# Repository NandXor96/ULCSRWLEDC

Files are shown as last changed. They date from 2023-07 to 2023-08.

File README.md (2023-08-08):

# ULCSRWLEDC
Ultra Low Cost Sound Reactive WLED Controller

## Features

- Small size
- Cheap components
- ICS-43434 MEMS Microphone (optional)
- MOSFET as "Relay"
- Mini Blade Fuse
- Solder Pads instead of Screw Terminal Blocks

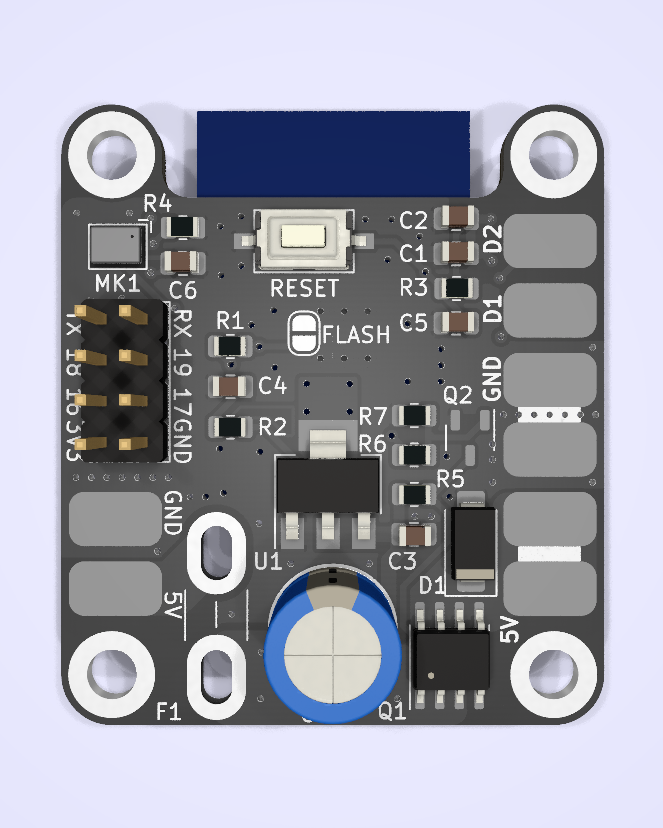
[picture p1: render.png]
Rendered picture of pcb


## BOM

| Reference | Value | Comment | Estimated Cost per piece |
|---|---|---|---|
| C1, C6 | 100nF | 0805 MLCC | 0.01€ |
| C2 | 10 - 22uF | 0805 MLCC | 0.10€ |
| C3, C4* | 22uF | 0805 MLCC | 0.10€ |
| C5 | 1uF | 0805 MLCC | 0.05€ |
| C7 | >=300uF | Electrolytic Cap D8.0 P3.5 | 0.15€ |
| D1 | SS14 | Schottky | 0.05€ |
| F1 | 2 - 10A | Mini Blade Fuse | 0.50€ |
| MK1** | ICS43434 | optional MEMS Microphone | 0.95 - 2.90€ |
| Q1 | - | SOIC-8 PMOS according to your needs - f.e. IRF7410 | 0.70 - 1.50€ |
| Q2 | - | SOT-23-3 NMOS according to your needs - f.e. IRLML6244 | 0.05 - 0.50€ |
| R1, R3, R5, R7 | 10k | 0805 Resistor | 0.01€ |
| R4 | 100k | 0805 Resistor | 0.01€ |
| R6 | 300R | 0805 Resistor | 0.01€ |
| R2* | 0.03-1R | optional 0805 Resistor | - |
| SW1 | - | Reset Switch SMD 6x3.5mm - f.e. PTS636 | 0.05 - 0.50€ |
| U1 | AMS1117-3.3 | SOT-223-3 LDO | 0.05 - 0.50€ | 
| U2 | ESP-WROOM-32 | ESP32-Module with antenna | 2.85€ |
| PCB | - | JLCPCB | 1.20€ |
|------|------|------|------|
|  |  |  | 5.12 - 10.89€ |

*If you have problems with the stability of the LDO you have two options:
1. Cut the trace resistance between R2 and try some 0805 resistors from 0.03-1ohm.
2. Choose tantal for C4 and bridge R2

** You can build it without the microphone. Then you don't need C6, R4 and MK1.

## Assembly

To assemble the PCB, I recommend using a hot plate or soldering oven for the upper side, and hand-soldering for the ESP32 on the back.
**Preheat** the PCB before soldering anything by hand and use a **powerful soldering iron**!  
Do NOT use a very small tip!

## Disclaimer

The circuit board provided on this GitHub repository is offered "as is," without any warranties or guarantees of any kind. By accessing and utilizing this circuit board, you acknowledge and agree that you do so at your own risk.

The creator and contributor of this repository, shall not be held responsible or liable for any damages, losses, or injuries that may occur as a result of building and / or using this circuit board. This includes but is not limited to any direct, indirect, consequential, or incidental damages.

Electricity is dangerous. Only attempt this project if you know what you're doing.

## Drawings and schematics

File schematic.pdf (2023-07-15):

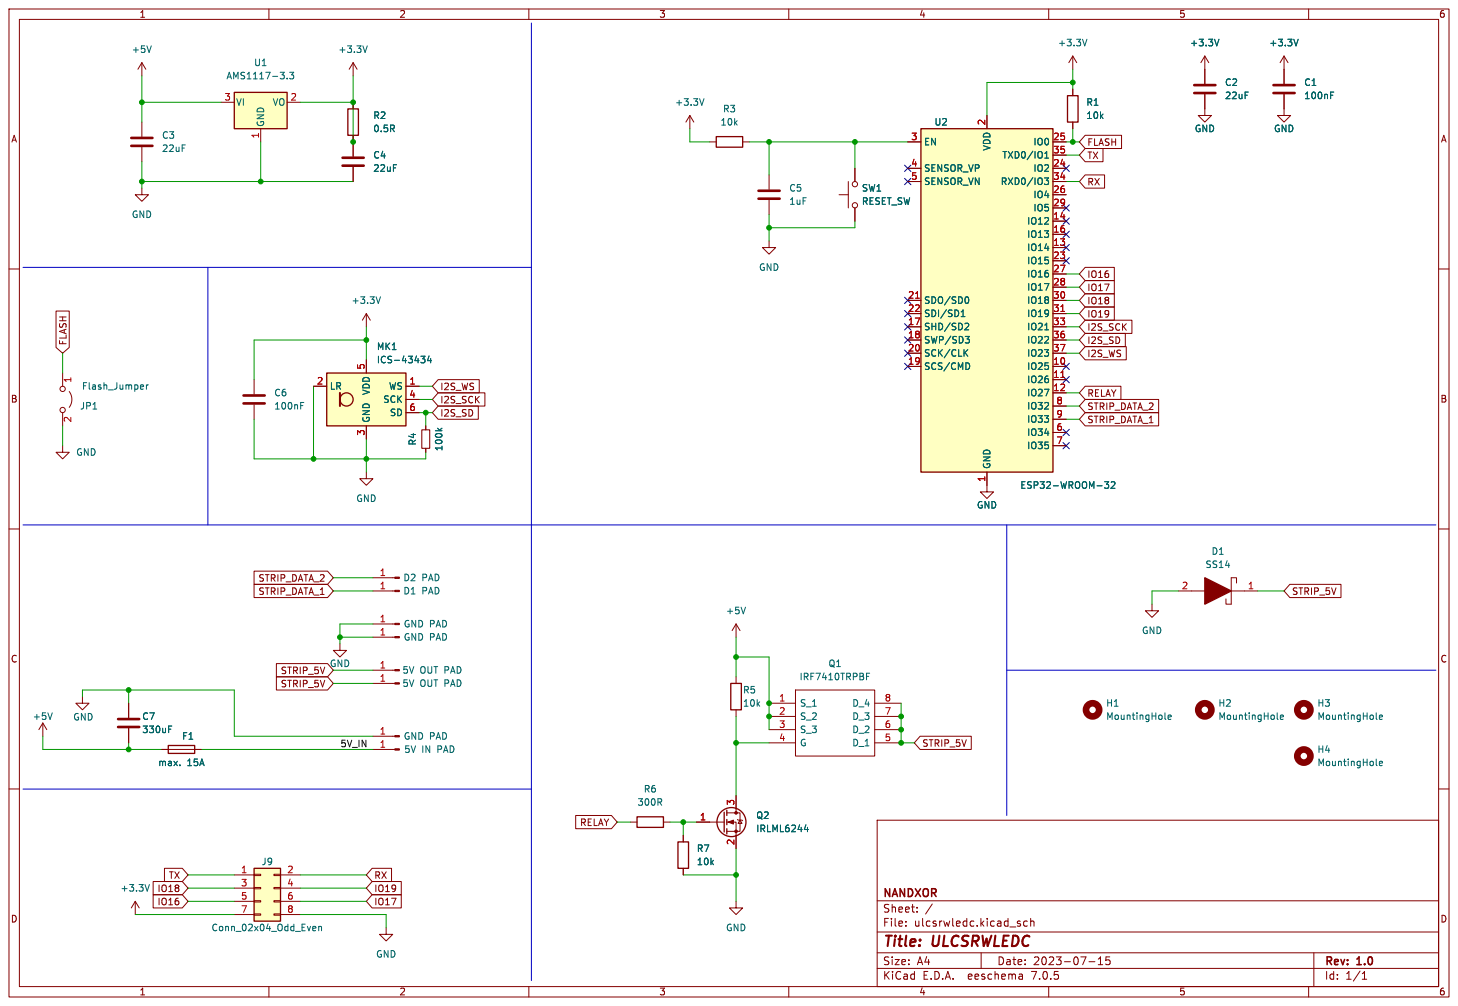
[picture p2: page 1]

File: ulcsrwledc.kicad_sch Sheet: / NANDXOR GND

2 SCK/CLK 20 SDO/SD0 21 SDI/SD1 22

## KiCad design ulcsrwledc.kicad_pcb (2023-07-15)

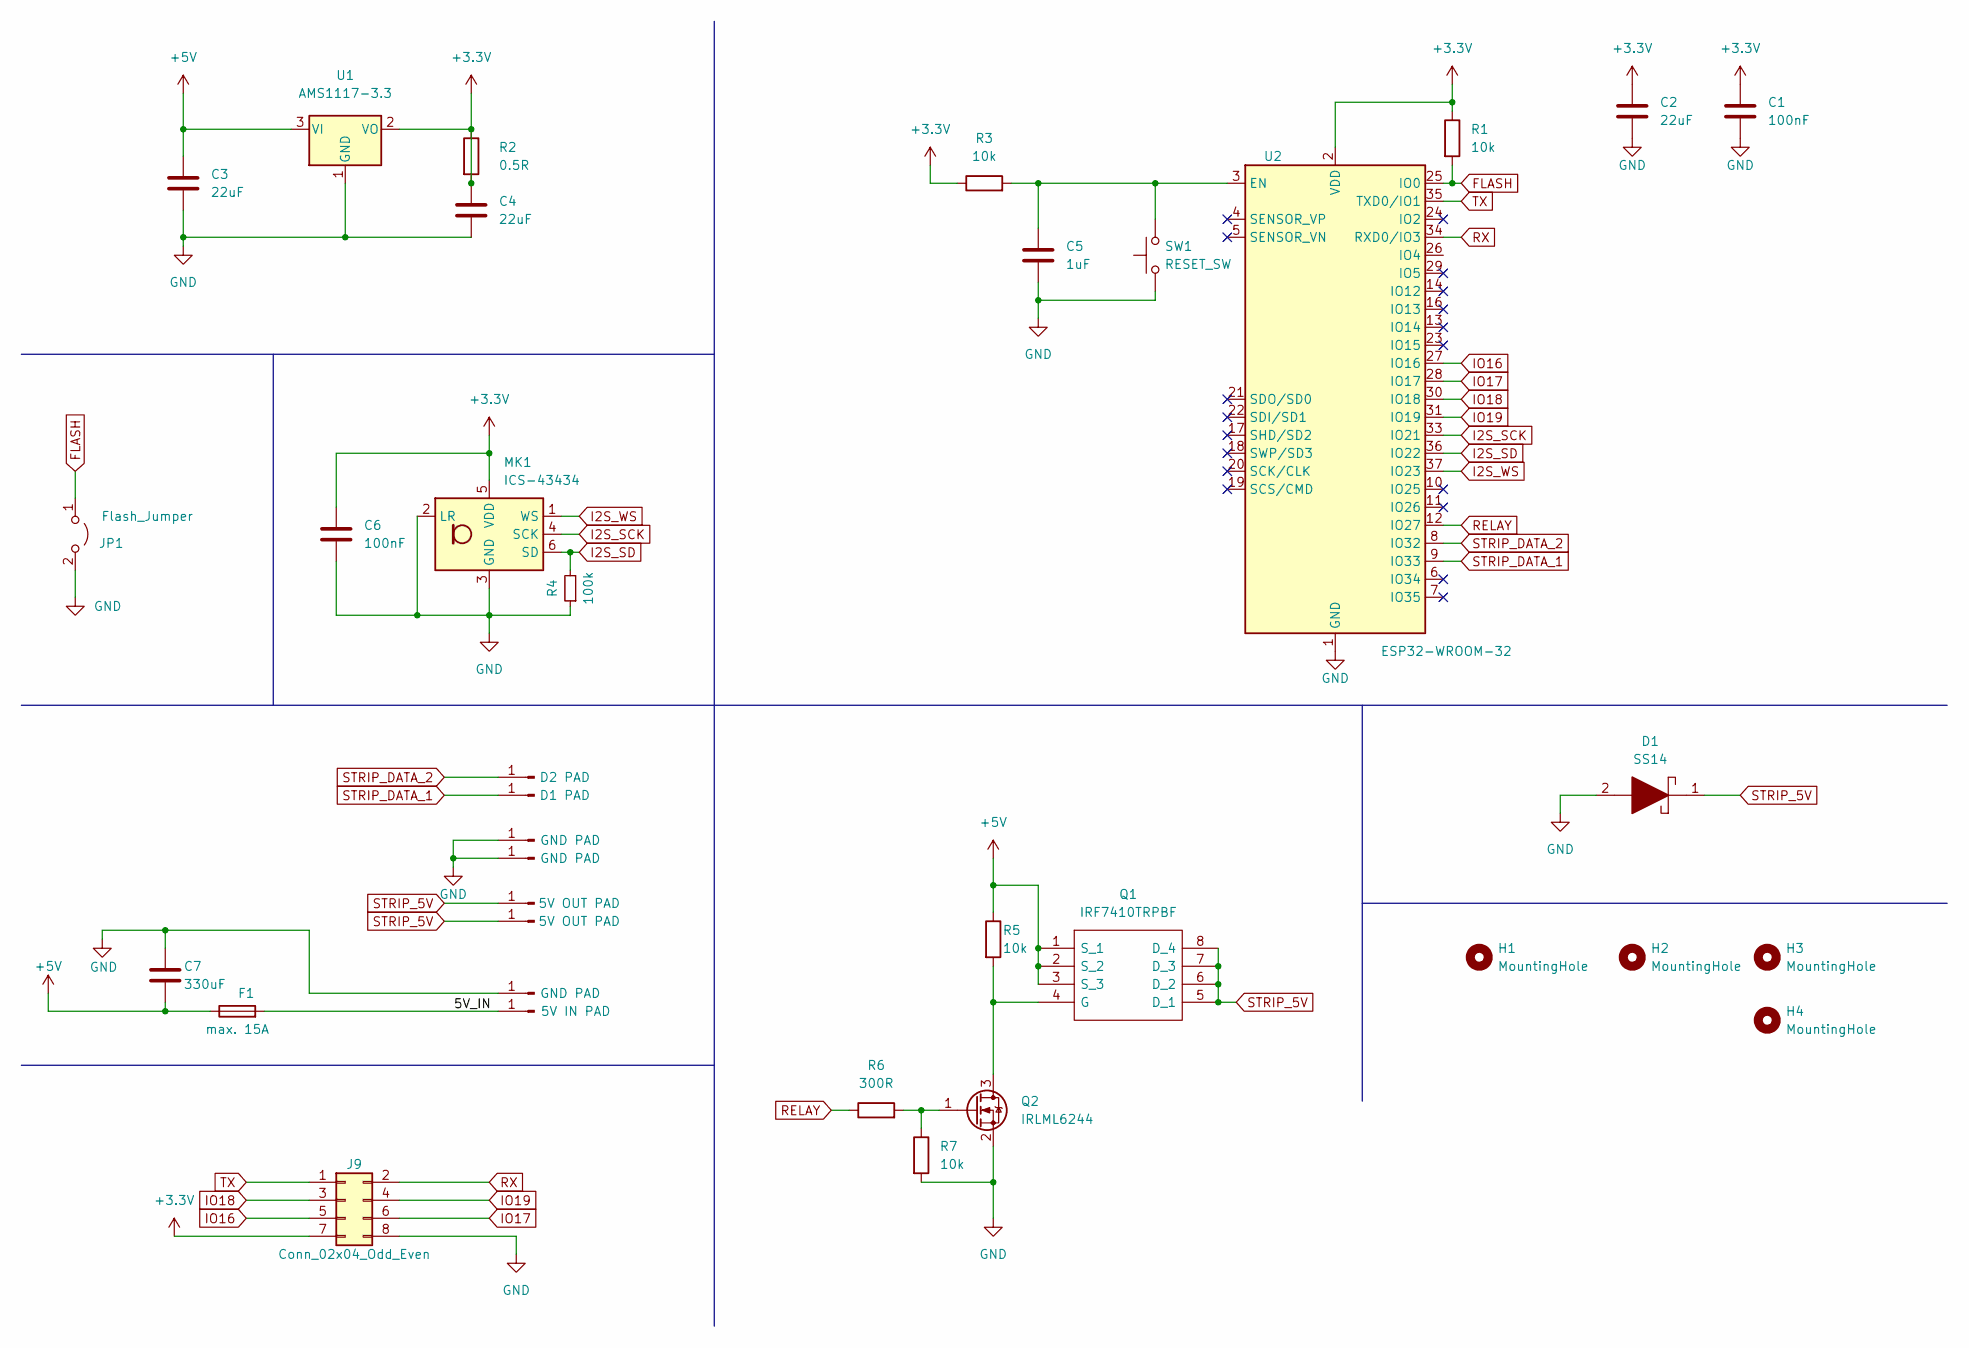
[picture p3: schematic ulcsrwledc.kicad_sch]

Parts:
C1, C6: 100nF; C_0805_2012Metric
C2, C3, C4: 22uF; C_0805_2012Metric
C5: 1uF; C_0805_2012Metric
C7: 330uF; CP_Radial_D8.0mm_P3.50mm
D1: SS14; D_SMA
F1: max. 15A; Fuse_Blade_Mini_directSolder
H1, H2, H3, H4: MountingHole; MountingHole_3.2mm_M3_DIN965_Pad_TopBottom
J1, J4: 5V OUT PAD; SolderWirePad_1x01_SMD_3x6mm
J2: D1 PAD; SolderWirePad_1x01_SMD_3x6mm
J3, J6, J7: GND PAD; SolderWirePad_1x01_SMD_3x6mm
J5: D2 PAD; SolderWirePad_1x01_SMD_3x6mm
J8: 5V IN PAD; SolderWirePad_1x01_SMD_3x6mm
J9: Conn_02x04_Odd_Even; PinHeader_2x04_P2.54mm_Vertical
JP1: Flash_Jumper; SolderJumper-2_P1.3mm_Open_RoundedPad1.0x1.5mm
MK1: ICS-43434; InvenSense_ICS-43434-6_3.5x2.65mm
Q1: IRF7410TRPBF; SO-8_3.9x4.9mm_P1.27mm
Q2: IRLML6244; SOT-23-3
R1, R3, R5, R7: 10k; R_0805_2012Metric
R2: 0.5R; R_0805_2012Metric
R4: 100k; R_0805_2012Metric
R6: 300R; R_0805_2012Metric
SW1: RESET_SW; SW_Tactile_SPST_NO_Straight_CK_PTS636Sx25SMTRLFS
U1: AMS1117-3.3; SOT-223-3_TabPin2
U2: ESP32-WROOM-32

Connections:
+3.3V: C1.2, C2.1, C4.1, C6.1, J9.7, MK1.5 (VDD), R1.1, R2.1, R2.2, R3.1, U1.2 (VO), U2.2 (VDD)
+5V: C3.1, C7.1, F1.1, Q1.1 (S_1), Q1.2 (S_2), Q1.3 (S_3), R5.1, U1.3 (VI)
/5V_IN: F1.2, J8.1
FLASH: JP1.1 (A), R1.2, U2.25 (IO0)
GND: C1.1, C2.2, C3.2, C4.2, C5.2, C6.2, C7.2, D1.2, J3.1, J6.1, J7.1, J9.8, JP1.2 (B), MK1.2 (LR), MK1.3 (GND), Q2.2 (S), R4.1, R7.2, SW1.1, U1.1 (GND), U2.1 (GND), U2.15 (GND), U2.38 (GND), U2.39 (GND)
I2S_SCK: MK1.4 (SCK), U2.33 (IO21)
I2S_SD: MK1.6 (SD), R4.2, U2.36 (IO22)
I2S_WS: MK1.1 (WS), U2.37 (IO23)
IO16: J9.5, U2.27 (IO16)
IO17: J9.6, U2.28 (IO17)
IO18: J9.3, U2.30 (IO18)
IO19: J9.4, U2.31 (IO19)
unnamed: Q1.4 (G), Q2.3 (D), R5.2
unnamed: Q2.1 (G), R6.2, R7.1
unnamed: C5.1, R3.2, SW1.2, U2.3 (EN)
RELAY: R6.1, U2.12 (IO27)
RX: J9.2, U2.34 (RXD0/IO3)
STRIP_5V: D1.1, J1.1, J4.1, Q1.5 (D_1), Q1.6 (D_2), Q1.7 (D_3), Q1.8 (D_4)
STRIP_DATA_1: J2.1, U2.9 (IO33)
STRIP_DATA_2: J5.1, U2.8 (IO32)
TX: J9.1, U2.35 (TXD0/IO1)

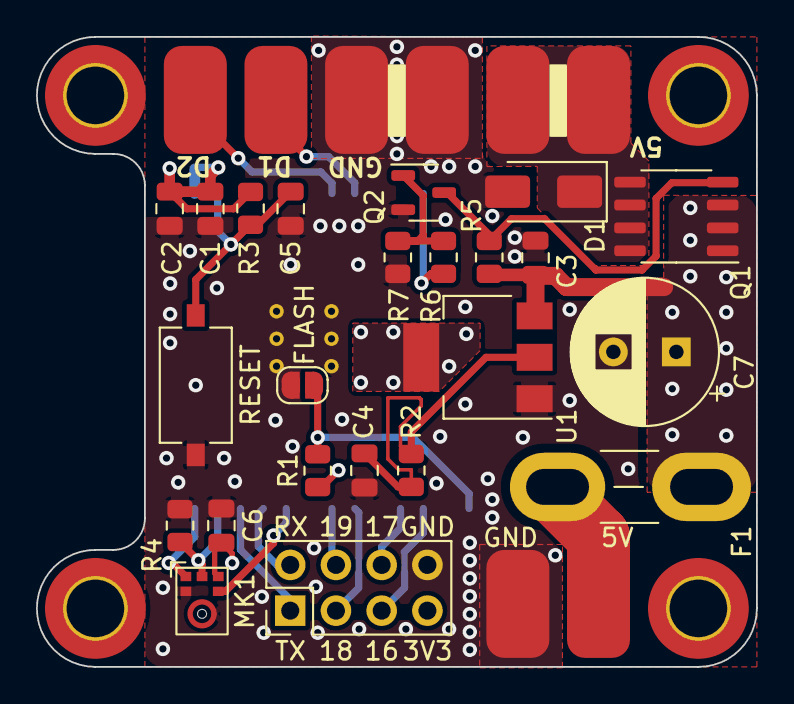
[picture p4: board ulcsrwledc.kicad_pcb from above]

Board: 4 copper layers, 40.0 x 35.0 mm, 36 parts (1 on the bottom side), 21 nets.
